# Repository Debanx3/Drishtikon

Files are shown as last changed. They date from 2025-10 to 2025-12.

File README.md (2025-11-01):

# Drishtikon:
## EdgeAI based human detection system <br>
 
+ The beginnings: ***Drishtikon*** is a framework consisting of two modules, the mainboard and the controller modules that can be powered directly from the 220VAC mains in dorms, libraries and canteens. The two boards communicate with each other using a BLE protocol and the mainboard is connected to the internet via Wi-Fi, it connects to the local network using hard coding.<br> <br>
  <div>
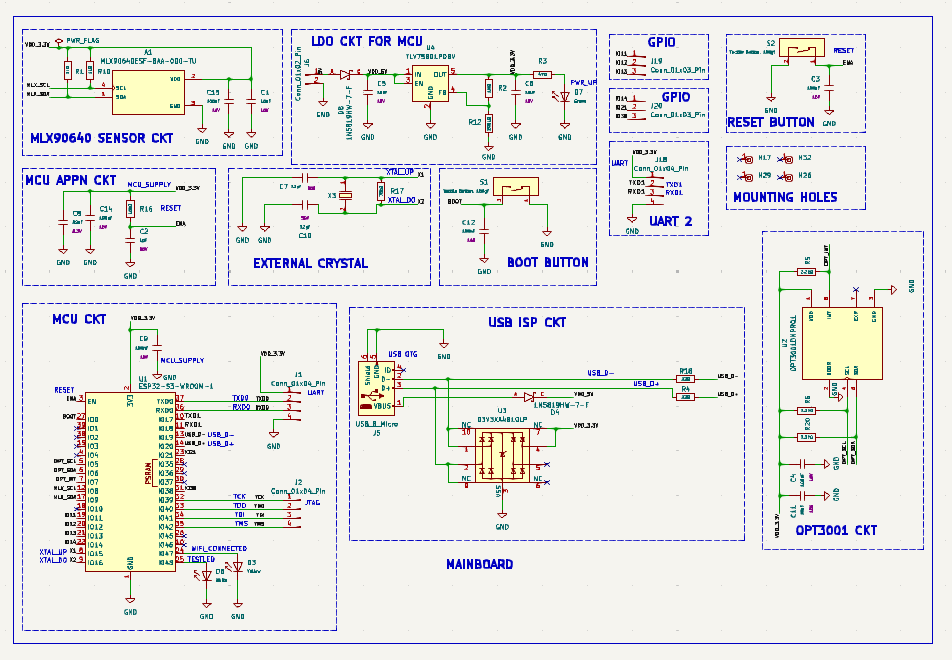
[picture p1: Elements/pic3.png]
  
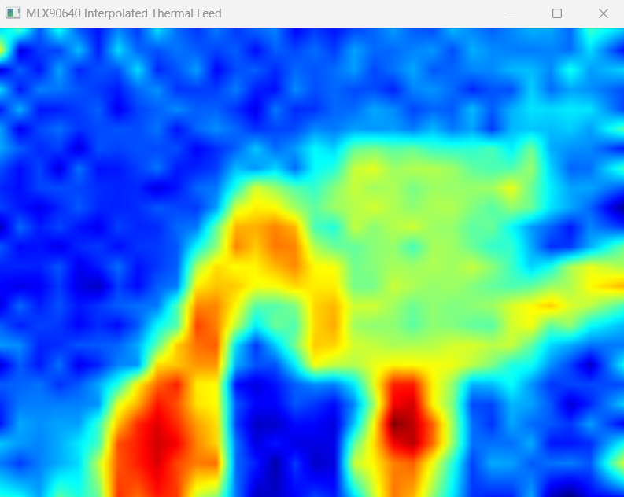
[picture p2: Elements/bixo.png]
  
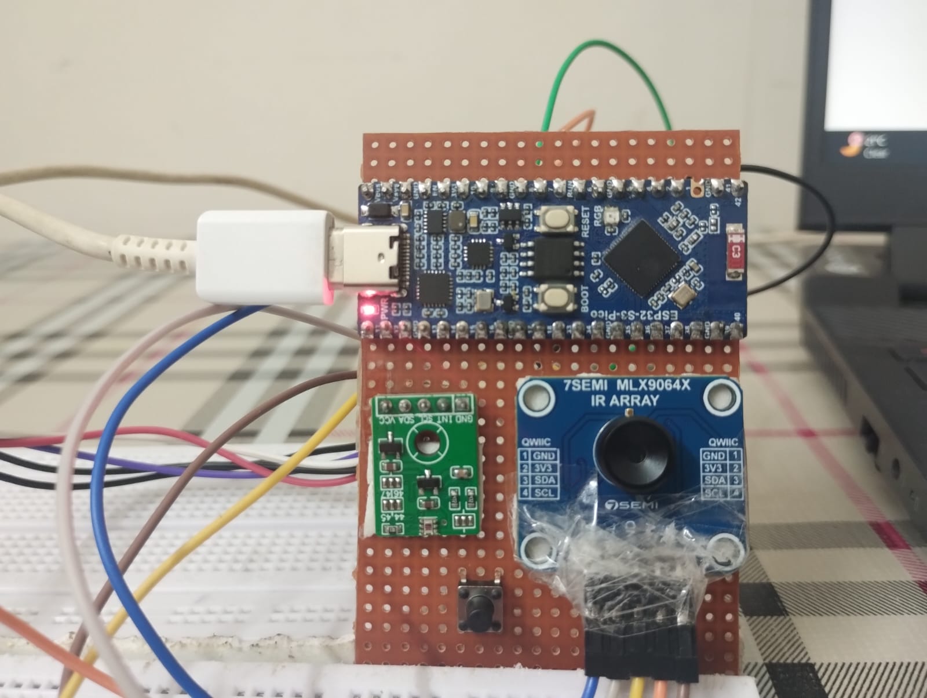
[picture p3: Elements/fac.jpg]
  
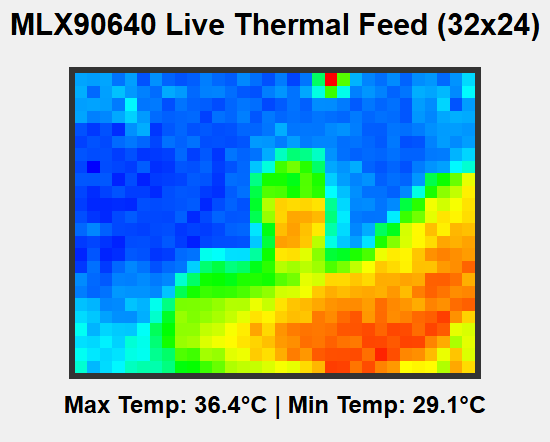
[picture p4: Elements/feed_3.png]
  
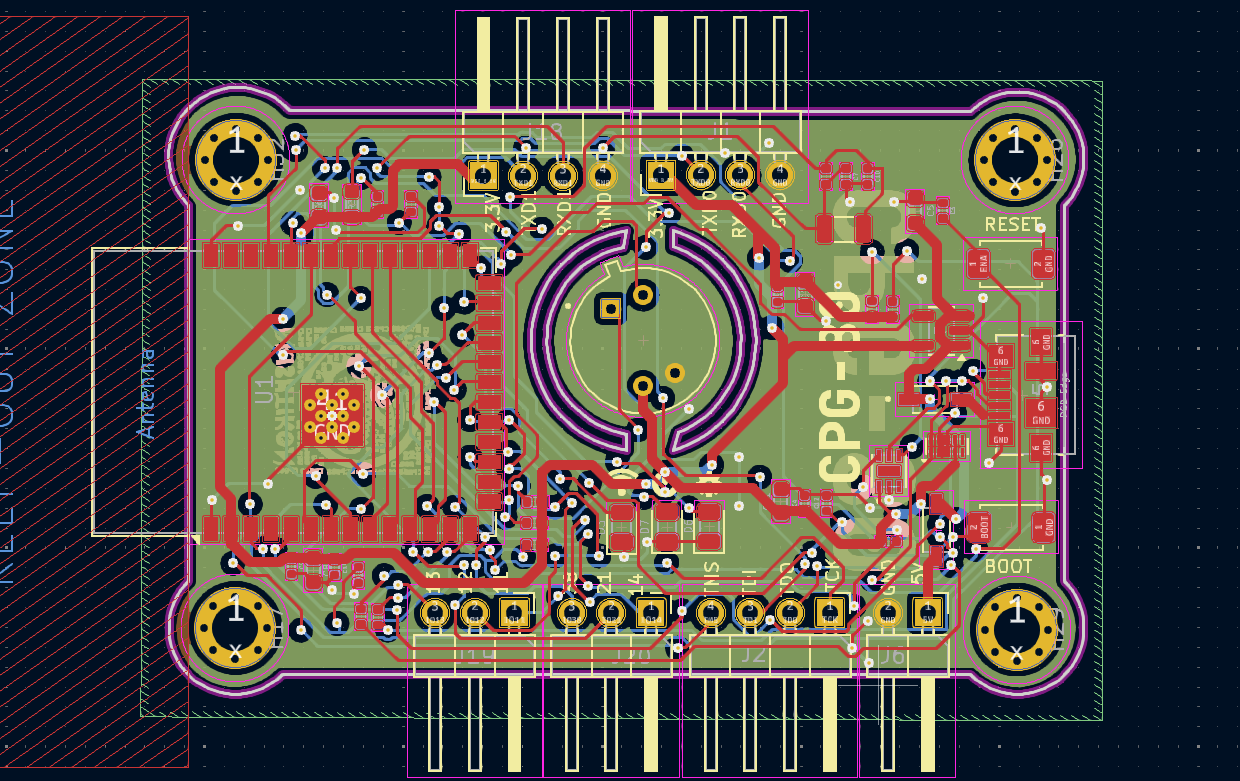
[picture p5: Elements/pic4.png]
  
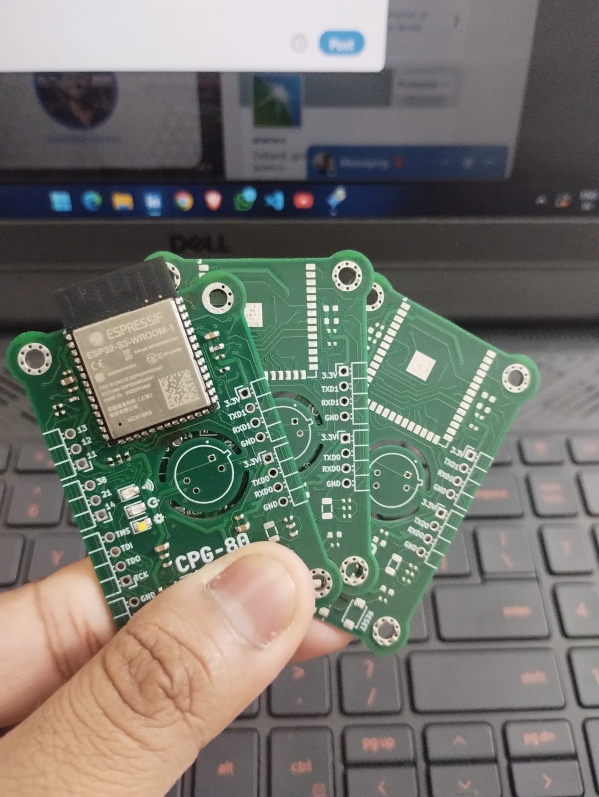
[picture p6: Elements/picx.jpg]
  
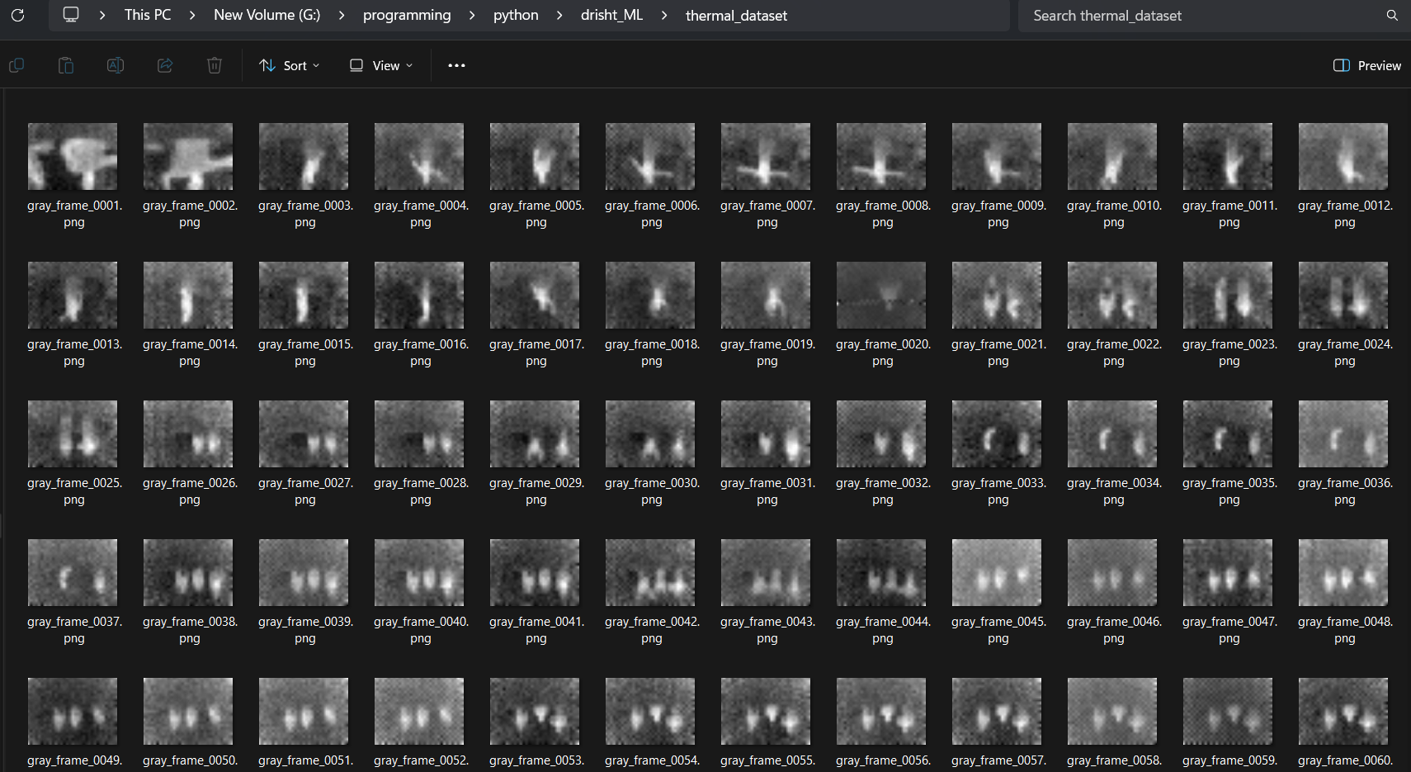
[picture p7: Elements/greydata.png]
  
  </div>

* License: MIT License
* Contact/Credits: Debanil Chanda, [DebanX3@github.com](mailto:debanx3@github.com)

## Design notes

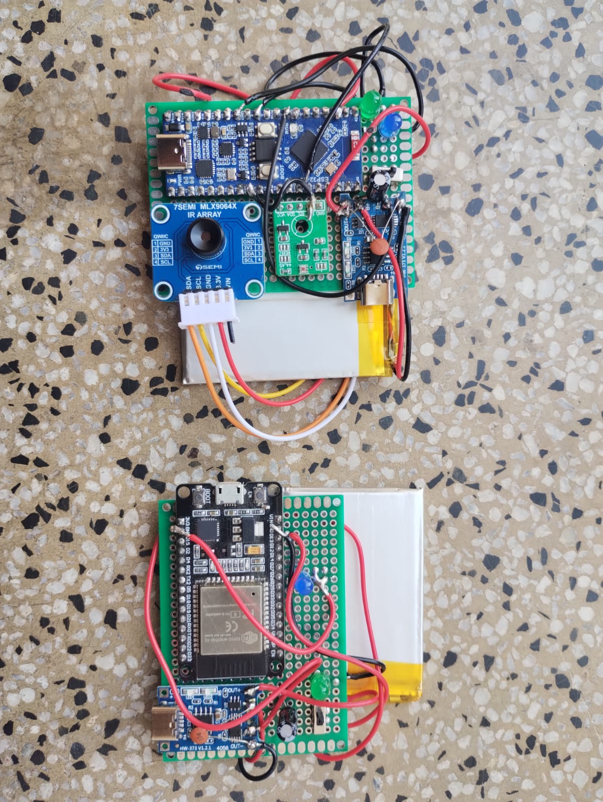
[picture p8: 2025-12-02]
Source_Code/Elements/A/drishtikon.jpg

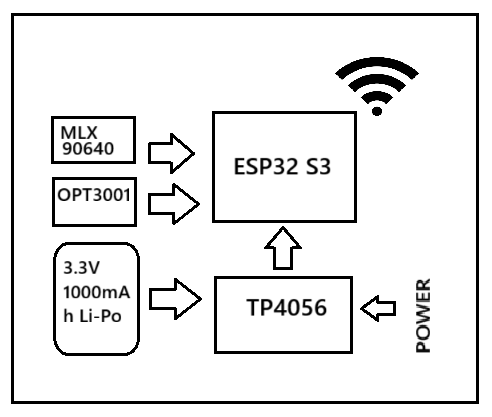
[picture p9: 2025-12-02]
Source_Code/Processing unit/pros.png

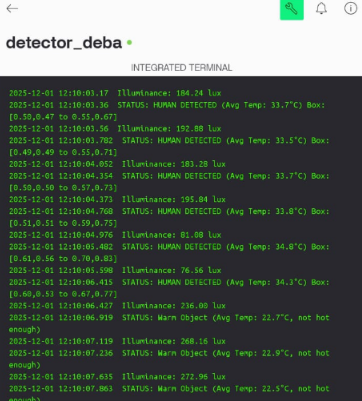
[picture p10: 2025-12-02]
Source_Code/Elements/A/blynk.png

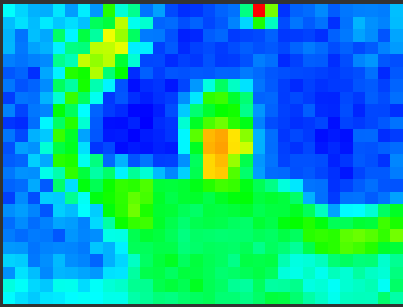
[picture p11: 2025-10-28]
Elements/feed_1.png

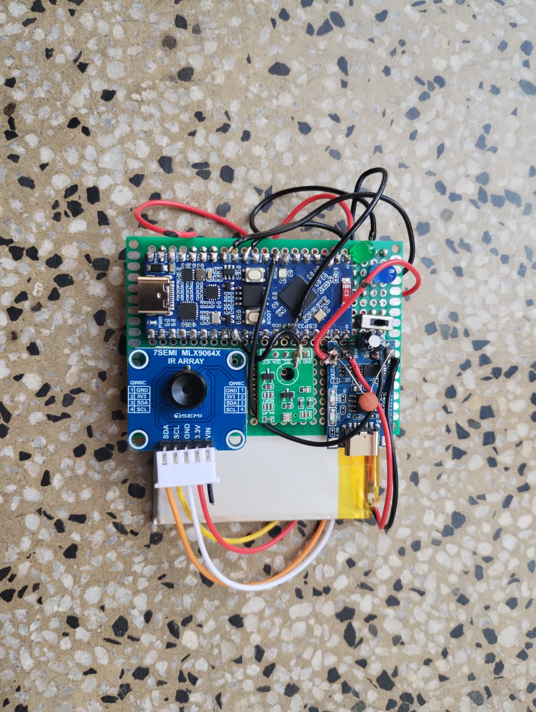
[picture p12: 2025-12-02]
Source_Code/Elements/A/processing.jpg

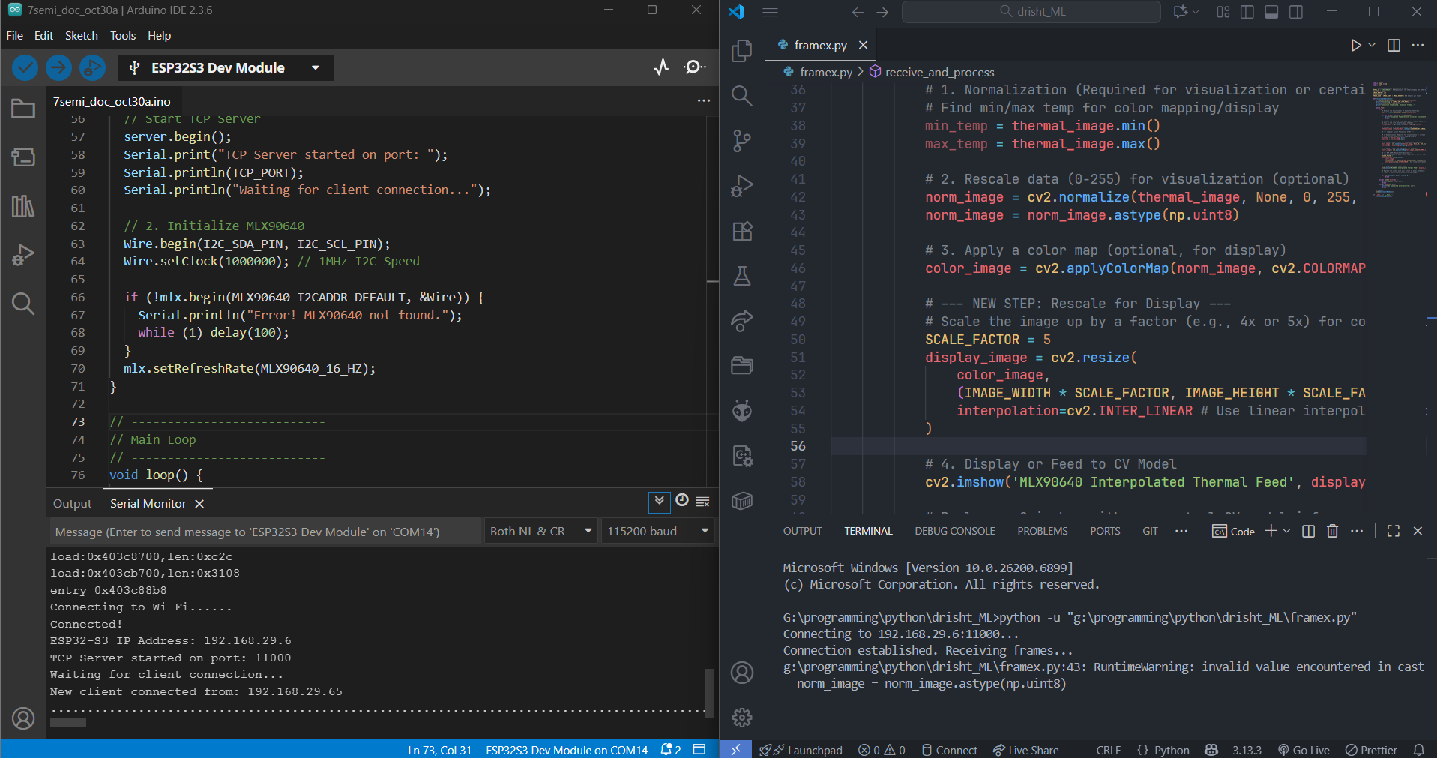
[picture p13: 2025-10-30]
Elements/bobu.png

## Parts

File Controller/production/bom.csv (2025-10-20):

Designator | Footprint | Quantity | Value | LCSC Part #
C13, C16, C19, C25 | C_0402 | 4 | 100nF | C1525
C17, C21 | C_0603 | 2 | 10uF | C19702
C18, C24 | C_0402 | 2 | 12pF | C1547
C20 | C_0402 | 1 | 1pF | C1550
C23 | C_0603 | 1 | 22uF | C59461
D1 | D_0805 | 1 | Green | C2297
D10, D9 | SOD3715X145N | 2 | 1N5819HW-7-F
D2 | D_0805 | 1 | White | C34499
D5 | D_0805 | 1 | Yellow | C2296
H22, H23, H24, H25 | Hole, 3mm | 4 | ~
J10, J9 | PinHeader_1x04_P2.54mm_Horizontal | 2 | Conn_01x04_Pin
J11 | USB_Micro-B_Molex_47346-0001 | 1 | USB_B_Micro
J13, J14, J15, J16 | PinHeader_1x05_P2.54mm_Vertical | 4 | Conn_01x05_Socket
J8 | PinHeader_1x02_P2.54mm_Horizontal | 1 | Conn_01x02_Pin
R11 | R_0603 | 1 | 47Ω | C23182
R14 | R_0402 | 1 | 1MΩ | C26083
R15 | R_0402 | 1 | 200kΩ | C25764
R19, R7 | R_0402 | 2 | 22Ω | C25092
R8 | R_0402 | 1 | 10kΩ | C25744
R9 | R_0402 | 1 | 75kΩ | C25798
S3, S4 | SW_TS-1088-AR02016 | 2 | Tactile Button, 160gf | C720477
U5 | ESP32-S3-WROOM-1 | 1 | ESP32-S3-WROOM-1
U6 | SOT-23-5 | 1 | TLV75801PDBV
U7 | Diodes_UDFN-10_1.0x2.5mm_P0.5mm | 1 | D3V3XA4B10LP
X1 | FC-135R_L3.2-W1.5 | 1 | Q13FC1350000400 | C32346

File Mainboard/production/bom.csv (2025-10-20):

Designator | Footprint | Quantity | Value | LCSC Part #
A1 | TO292P930H600-4 | 1 | MLX90640ESF-BAA-000-TU
C1, C11, C5, C6 | C_0603 | 4 | 10uF | C19702
C10, C7 | C_0402 | 2 | 12pF | C1547
C12, C14, C15, C3, C4, C9 | C_0402 | 6 | 100nF | C1525
C2 | C_0402 | 1 | 1pF | C1550
C8 | C_0603 | 1 | 22uF | C59461
D3 | D_0805 | 1 | Yellow | C2296
D4, D8 | SOD3715X145N | 2 | 1N5819HW-7-F
D6 | D_0805 | 1 | White | C34499
D7 | D_0805 | 1 | Green | C2297
H17, H26, H29, H32 | Hole, 3mm | 4 | ~
J1, J18, J2 | PinHeader_1x04_P2.54mm_Horizontal | 3 | Conn_01x04_Pin
J19, J20 | PinHeader_1x03_P2.54mm_Horizontal | 2 | Conn_01x03_Pin
J5 | USB_Micro-B_Molex_47346-0001 | 1 | USB_B_Micro
J6 | PinHeader_1x02_P2.54mm_Horizontal | 1 | Conn_01x02_Pin
R1, R10 | R_0402 | 2 | 1kΩ | C11702
R12 | R_0402 | 1 | 200kΩ | C25764
R16 | R_0402 | 1 | 10kΩ | C25744
R17 | R_0402 | 1 | 75kΩ | C25798
R18, R4 | R_0402 | 2 | 22Ω | C25092
R2 | R_0402 | 1 | 1MΩ | C26083
R20, R5, R6 | R_0402 | 3 | 2.2kΩ | C25879
R3 | R_0603 | 1 | 47Ω | C23182
S1, S2 | SW_TS-1088-AR02016 | 2 | Tactile Button, 160gf | C720477
U1 | ESP32-S3-WROOM-1 | 1 | ESP32-S3-WROOM-1
U2 | SON65P200X200X65-7N | 1 | OPT3001DNPRQ1
U3 | Diodes_UDFN-10_1.0x2.5mm_P0.5mm | 1 | D3V3XA4B10LP
U4 | SOT-23-5 | 1 | TLV75801PDBV
X3 | FC-135R_L3.2-W1.5 | 1 | Q13FC1350000400 | C32346

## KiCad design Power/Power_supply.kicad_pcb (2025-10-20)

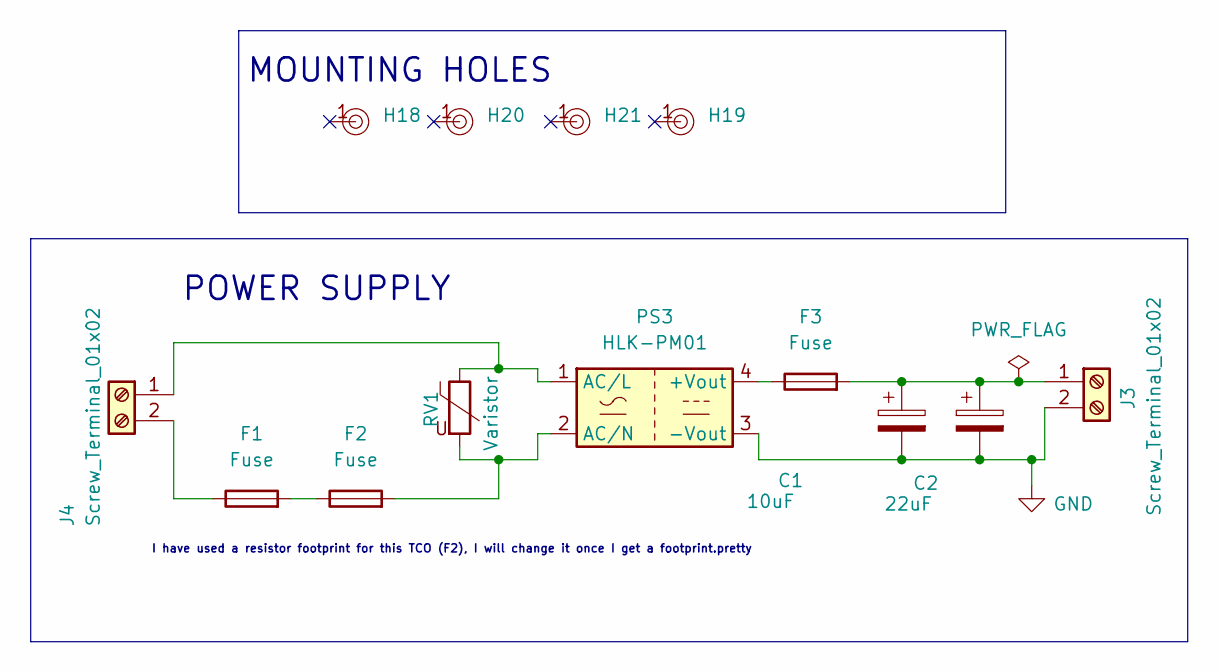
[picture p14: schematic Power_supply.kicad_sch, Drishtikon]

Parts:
C1: 10uF; CP_Radial_D8.0mm_P3.50mm
C2: 22uF; CP_Radial_D8.0mm_P3.50mm
F1, F3: Fuse; Fuseholder_Cylinder-5x20mm_Stelvio-Kontek_PTF78_Horizontal_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
F2: Fuse; R_Axial_DIN0309_L9.0mm_D3.2mm_P12.70mm_Horizontal
H18, H19, H20, H21: Hole, 3mm
J3, J4: Screw_Terminal_01x02; TerminalBlock_Phoenix_MKDS-1,5-2-5.08_1x02_P5.08mm_Horizont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
PS3: HLK-PM01; Converter_ACDC_Hi-Link_HLK-PMxx
RV1: Varistor; RV_Disc_D12mm_W3.9mm_P7.5mm

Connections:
GND: C1.2, C2.2, J3.2, PS3.3 (-Vout)
unnamed: F1.2, F2.1
unnamed: C1.1, C2.1, F3.2, J3.1
unnamed: J4.1, PS3.1 (AC/L), RV1.1
unnamed: F1.1, J4.2
unnamed: F3.1, PS3.4 (+Vout)
unnamed: F2.2, PS3.2 (AC/N), RV1.2

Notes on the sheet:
I have used a resistor footprint for this TCO (F2), I will change it once I get a footprint.pretty
POWER SUPPLY
MOUNTING HOLES

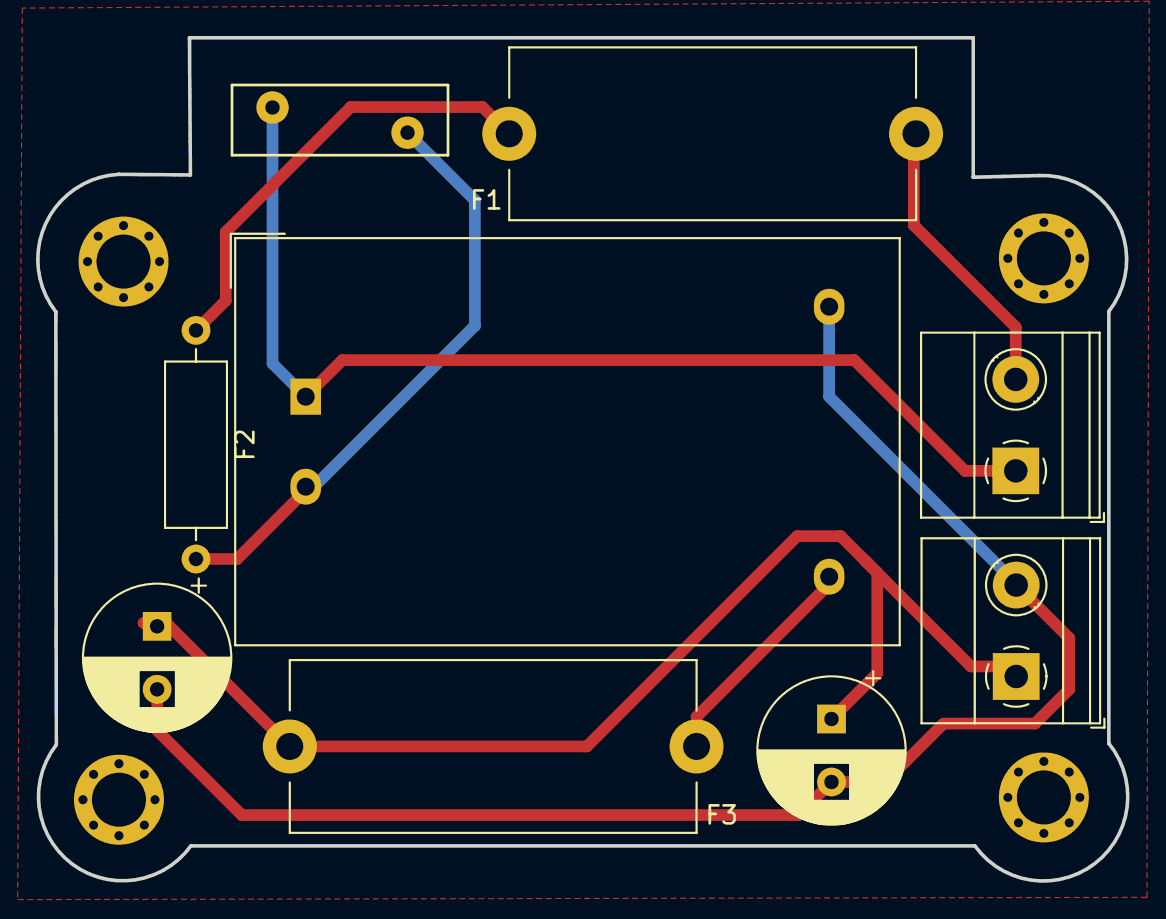
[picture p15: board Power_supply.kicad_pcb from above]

Board: 2 copper layers, 60.6 x 46.8 mm, 13 parts (0 on the bottom side), 7 nets.

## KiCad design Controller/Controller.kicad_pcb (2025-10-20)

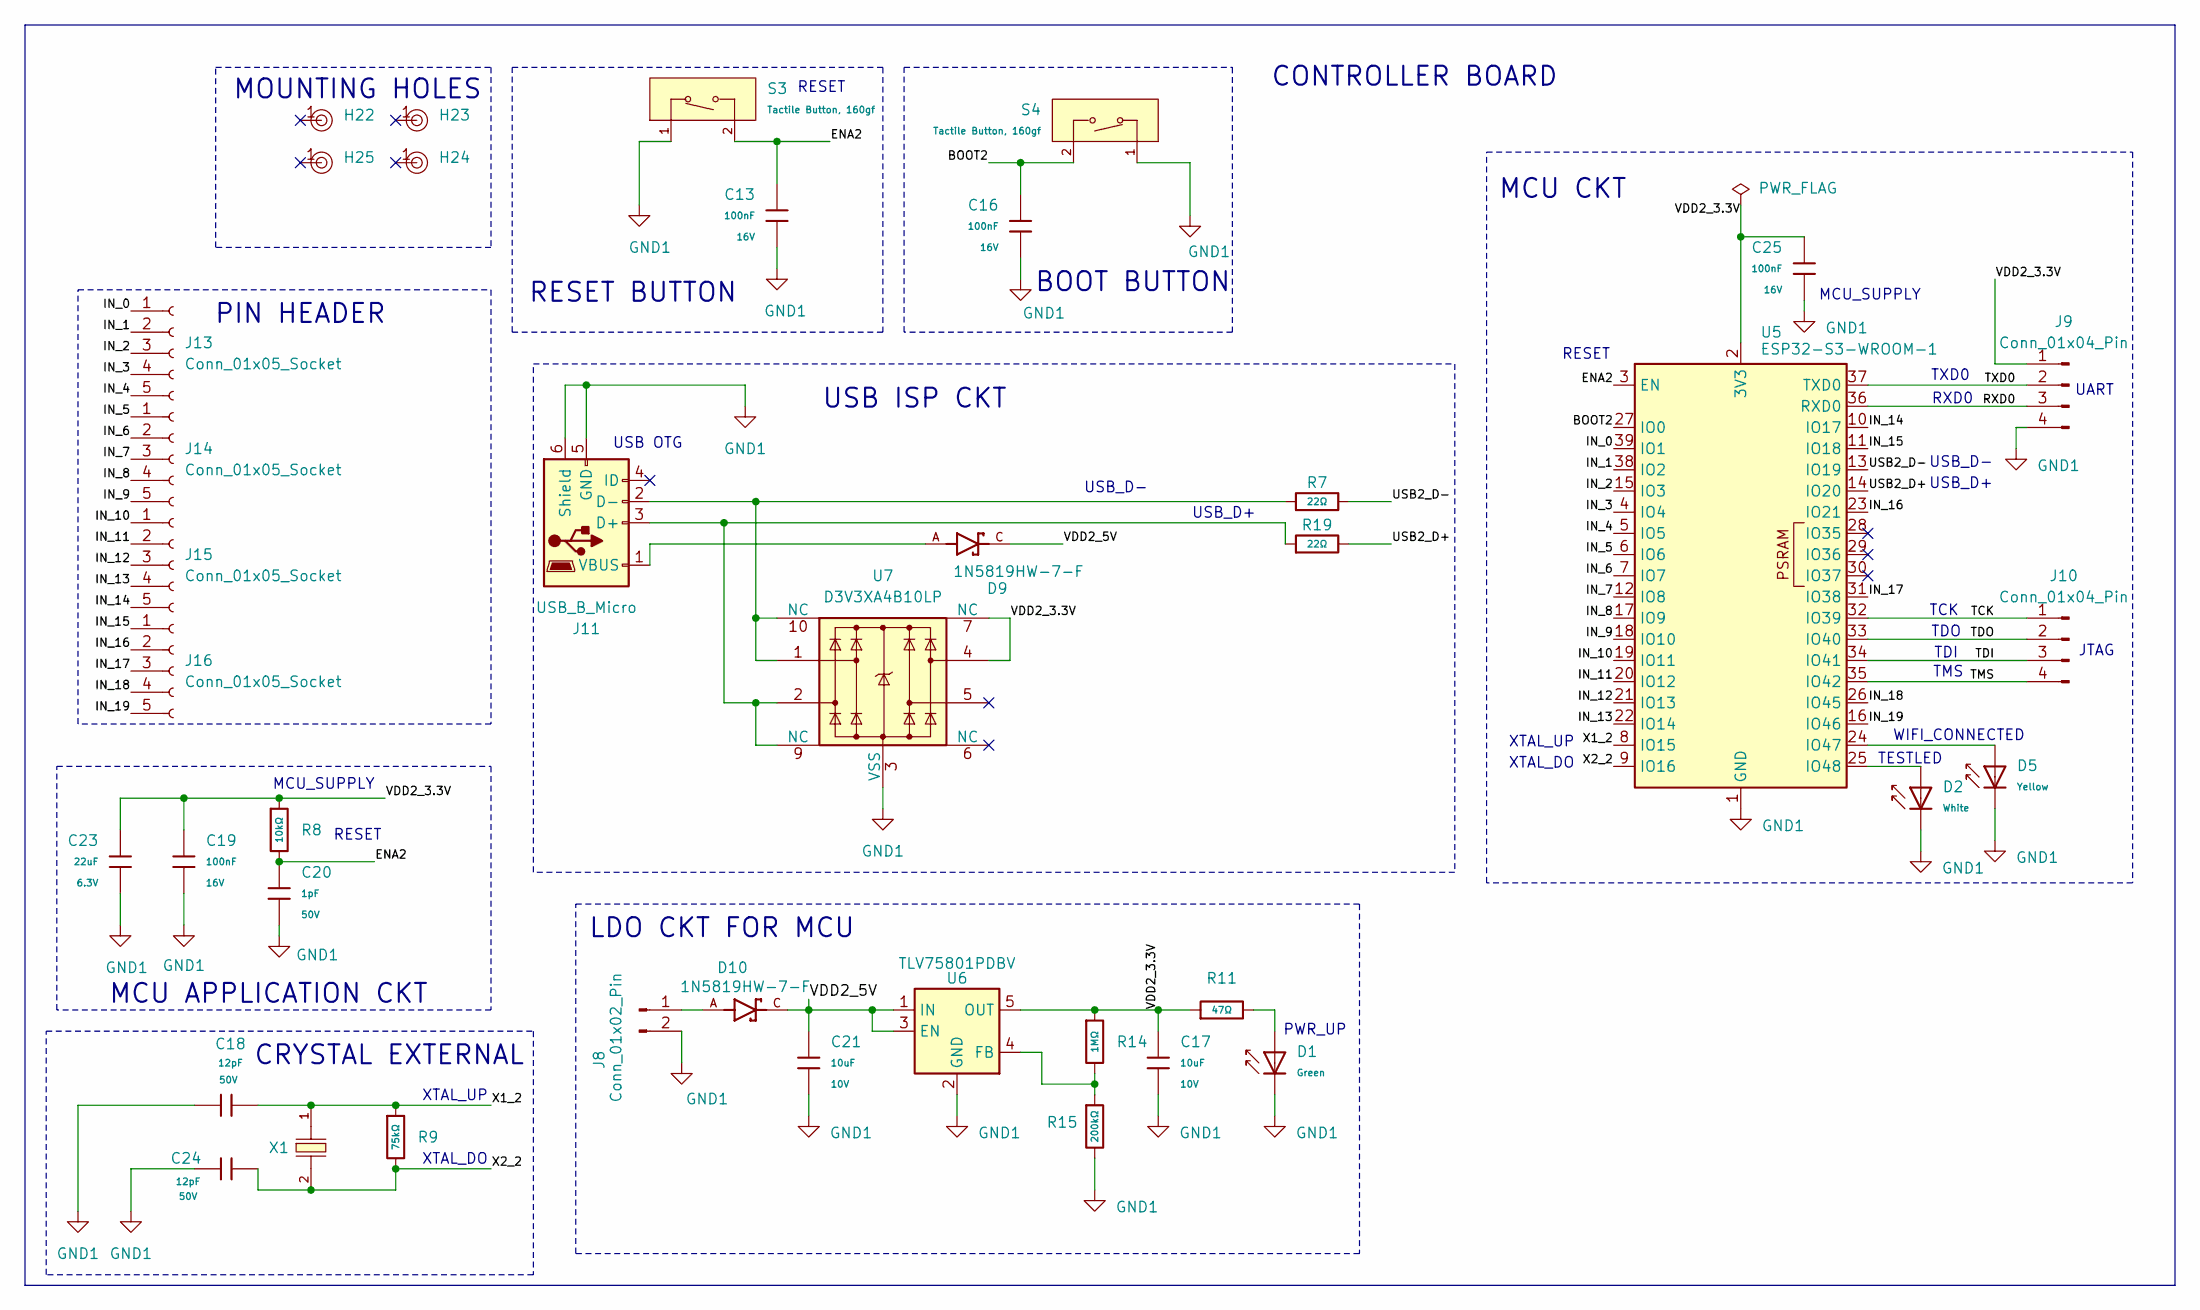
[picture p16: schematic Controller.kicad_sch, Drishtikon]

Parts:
C13, C16, C19, C25: 100nF; C_0402; Voltage Rated 16V; Tolerance ±10%; Part CL05B104KO5NNNC; LCSC C1525
C17, C21: 10uF; C_0603; Voltage Rated 10V; Tolerance ±10%; Part CL10A106KP8NNNC; LCSC C19702
C18, C24: 12pF; C_0402; Voltage Rated 50V; Tolerance ±5%; Part 0402CG120J500NT; LCSC C1547
C20: 1pF; C_0402; Voltage Rated 50V; Part 0402CG1R0C500NT; LCSC C1550
C23: 22uF; C_0603; Voltage Rated 6.3V; Tolerance ±20%; Part CL10A226MQ8NRNC; LCSC C59461
D1: Green; D_0805; Part KT-0805G; LCSC C2297
D2: White; D_0805; Part KT-0805W; LCSC C34499
D5: Yellow; D_0805; Part KT-0805Y; LCSC C2296
D9, D10: 1N5819HW-7-F; SOD3715X145N; PARTREV 18-2
H22, H23, H24, H25: Hole, 3mm
J8: Conn_01x02_Pin; PinHeader_1x02_P2.54mm_Horizontal
J9, J10: Conn_01x04_Pin; PinHeader_1x04_P2.54mm_Horizontal
J11: USB_B_Micro; USB_Micro-B_Molex_47346-0001
J13, J14, J15, J16: Conn_01x05_Socket; PinHeader_1x05_P2.54mm_Vertical
R7, R19: 22Ω; R_0402; Overload Voltage (Max) 50V; Tolerance ±1%; Part 0402WGF220JTCE; LCSC C25092
R8: 10kΩ; R_0402; Overload Voltage (Max) 50V; Tolerance ±1%; Part 0402WGF1002TCE; LCSC C25744
R9: 75kΩ; R_0402; Overload Voltage (Max) 50V; Tolerance ±1%; Part 0402WGF7502TCE; LCSC C25798
R11: 47Ω; R_0603; Overload Voltage (Max) 75V; Tolerance ±1%; Part 0603WAF470JT5E; LCSC C23182
R14: 1MΩ; R_0402; Overload Voltage (Max) 50V; Tolerance ±1%; Part 0402WGF1004TCE; LCSC C26083
R15: 200kΩ; R_0402; Overload Voltage (Max) 50V; Tolerance ±1%; Part 0402WGF2003TCE; LCSC C25764
S3, S4: Tactile Button, 160gf; SW_TS-1088-AR02016; Voltage Rating (Dc) 12V; Part TS-1088-AR02016; LCSC C720477
U5: ESP32-S3-WROOM-1
U6: TLV75801PDBV; SOT-23-5
U7: D3V3XA4B10LP; Diodes_UDFN-10_1.0x2.5mm_P0.5mm
X1: Q13FC1350000400; FC-135R_L3.2-W1.5; Frequency Tolerance ±20ppm; Part Q13FC13500004; LCSC C32346

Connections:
/BOOT2: C16.1, S4.2 (B), U5.27 (IO0)
/ENA2: C13.1, C20.2, R8.2, S3.2 (B), U5.3 (EN)
/IN_0: J13.1, U5.39 (IO1)
/IN_1: J13.2, U5.38 (IO2)
/IN_2: J13.3, U5.15 (IO3)
/IN_3: J13.4, U5.4 (IO4)
/IN_4: J13.5, U5.5 (IO5)
/IN_5: J14.1, U5.6 (IO6)
/IN_6: J14.2, U5.7 (IO7)
/IN_7: J14.3, U5.12 (IO8)
/IN_8: J14.4, U5.17 (IO9)
/IN_9: J14.5, U5.18 (IO10)
/IN_10: J15.1, U5.19 (IO11)
/IN_11: J15.2, U5.20 (IO12)
/IN_12: J15.3, U5.21 (IO13)
/IN_13: J15.4, U5.22 (IO14)
/IN_14: J15.5, U5.10 (IO17)
/IN_15: J16.1, U5.11 (IO18)
/IN_16: J16.2, U5.23 (IO21)
/IN_17: J16.3, U5.31 (IO38)
/IN_18: J16.4, U5.26 (IO45)
/IN_19: J16.5, U5.16 (IO46)
/RXD0: J9.3, U5.36 (RXD0)
/TCK: J10.1, U5.32 (IO39)
/TDI: J10.3, U5.34 (IO41)
/TDO: J10.2, U5.33 (IO40)
/TMS: J10.4, U5.35 (IO42)
/TXD0: J9.2, U5.37 (TXD0)
/USB2_D+: R19.2, U5.14 (IO20)
/USB2_D-: R7.2, U5.13 (IO19)
/VDD2_3.3V: C17.1, C19.1, C23.1, C25.1, J9.1, R8.1, R11.1, R14.1, U5.2 (3V3), U6.5 (OUT), U7.4, U7.7 (NC)
/VDD2_5V: C21.1, D9.C, D10.C, U6.1 (IN), U6.3 (EN)
/X1_2: C18.2, R9.1, U5.8 (IO15), X1.1
/X2_2: C24.2, R9.2, U5.9 (IO16), X1.2
GND1: C13.2, C16.2, C17.2, C18.1, C19.2, C20.1, C21.2, C23.2, C24.1, C25.2, D1.1, D2.1, D5.1, J8.2, J9.4, J11.5 (GND), J11.6 (Shield), R15.2, S3.1 (A), S4.1 (A), U5.1 (GND), U5.40 (GND), U5.41 (GND), U6.2 (GND), U7.3 (VSS), U7.8 (VSS)
unnamed: D1.2, R11.2
unnamed: D10.A, J8.1
unnamed: J11.3 (D+), R19.1, U7.2, U7.9 (NC)
unnamed: J11.2 (D-), R7.1, U7.1, U7.10 (NC)
unnamed: D9.A, J11.1 (VBUS)
unnamed: D5.2, U5.24 (IO47)
unnamed: D2.2, U5.25 (IO48)
unnamed: R14.2, R15.1, U6.4 (FB)

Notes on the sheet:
RESET
MCU_SUPPLY
UART
MCU CKT
TMS
TDI
MCU APPLICATION CKT
TDO
USB_D+
TESTLED
JTAG
BOOT BUTTON
LDO CKT FOR MCU
CONTROLLER BOARD
RESET BUTTON
WIFI_CONNECTED
MOUNTING HOLES
USB_D-
CRYSTAL EXTERNAL
XTAL_UP
PWR_UP
PIN HEADER
USB ISP CKT
USB OTG
TCK
XTAL_DO
TXD0
RXD0

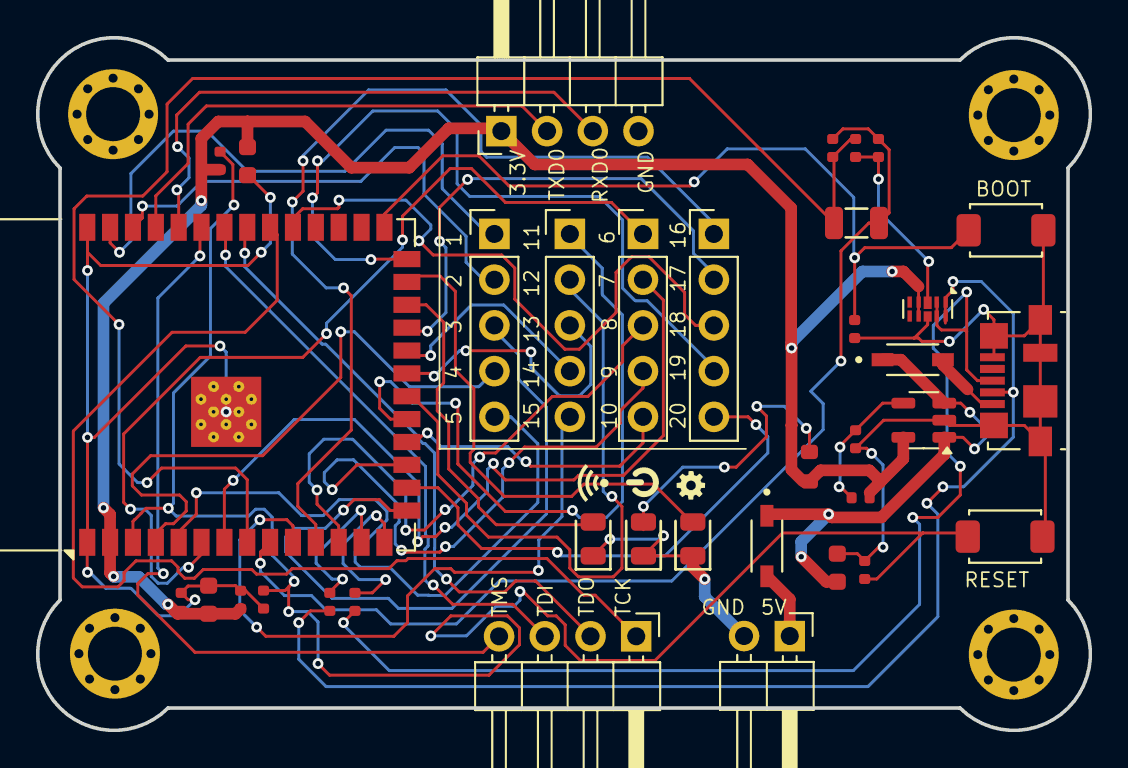
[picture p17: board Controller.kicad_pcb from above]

Board: 4 copper layers, 58.5 x 38.5 mm, 40 parts (0 on the bottom side), 43 nets.

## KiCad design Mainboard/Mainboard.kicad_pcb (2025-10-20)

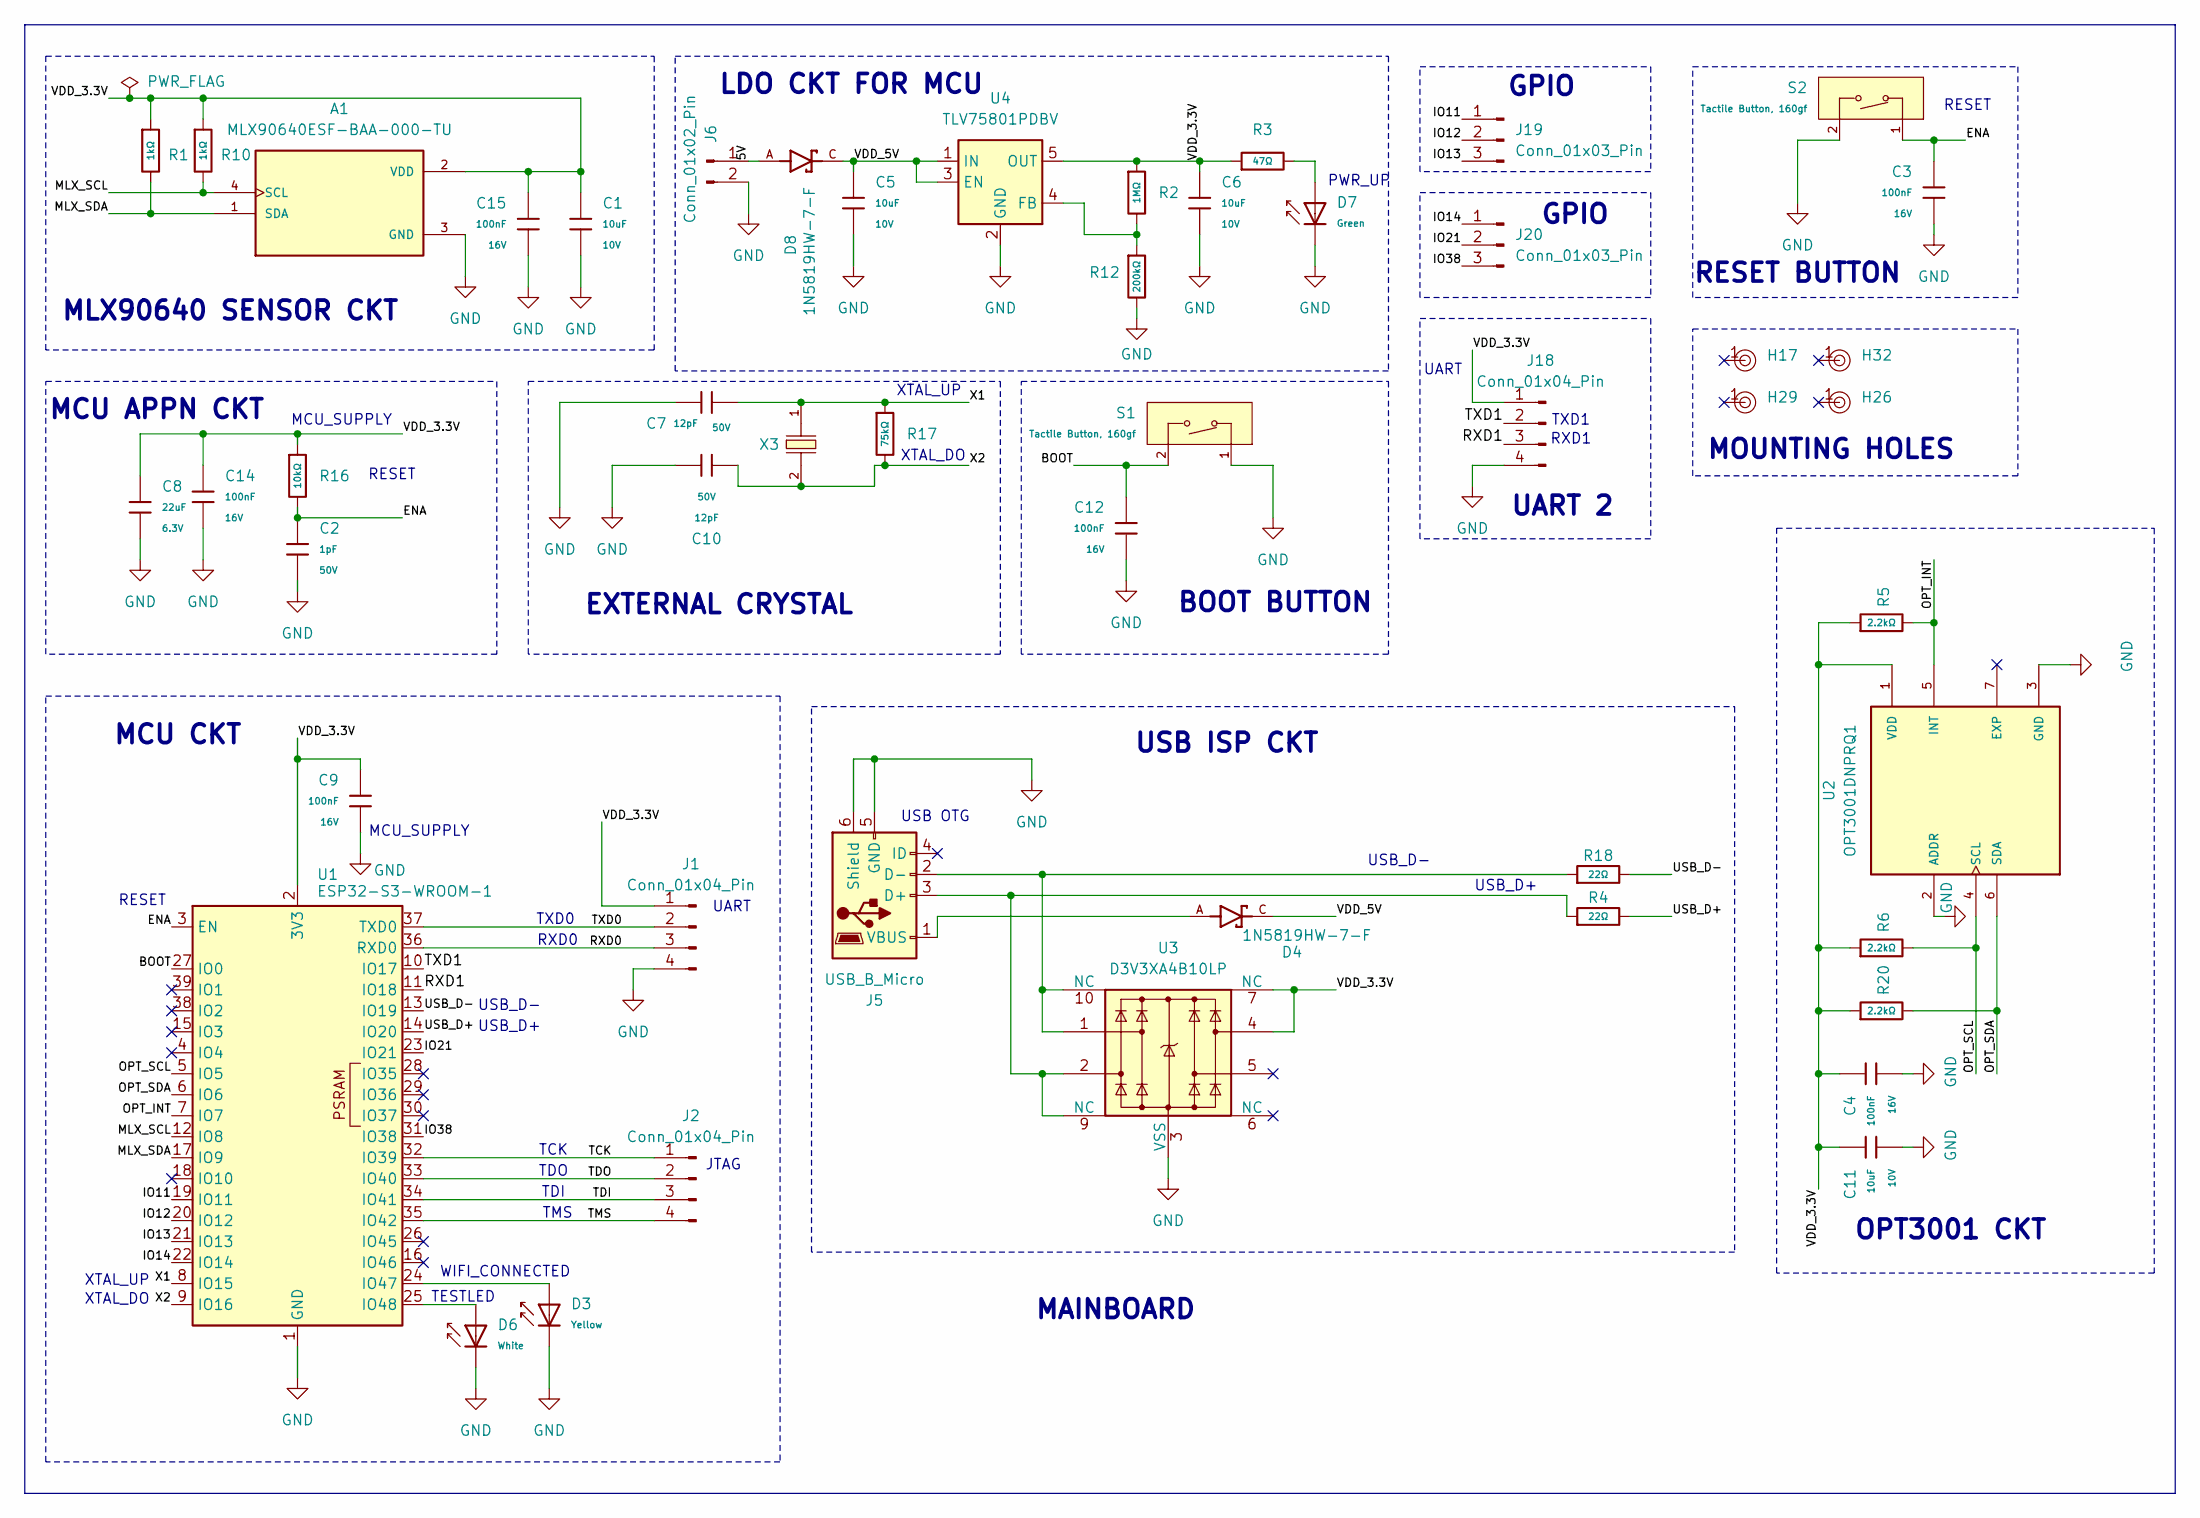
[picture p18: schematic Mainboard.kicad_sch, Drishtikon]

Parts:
A1: MLX90640ESF-BAA-000-TU; TO292P930H600-4; PARTREV 11
C1, C5, C6, C11: 10uF; C_0603; Voltage Rated 10V; Tolerance ±10%; Part CL10A106KP8NNNC; LCSC C19702
C2: 1pF; C_0402; Voltage Rated 50V; Part 0402CG1R0C500NT; LCSC C1550
C3, C4, C9, C12, C14, C15: 100nF; C_0402; Voltage Rated 16V; Tolerance ±10%; Part CL05B104KO5NNNC; LCSC C1525
C7, C10: 12pF; C_0402; Voltage Rated 50V; Tolerance ±5%; Part 0402CG120J500NT; LCSC C1547
C8: 22uF; C_0603; Voltage Rated 6.3V; Tolerance ±20%; Part CL10A226MQ8NRNC; LCSC C59461
D3: Yellow; D_0805; Part KT-0805Y; LCSC C2296
D4, D8: 1N5819HW-7-F; SOD3715X145N; PARTREV 18-2
D6: White; D_0805; Part KT-0805W; LCSC C34499
D7: Green; D_0805; Part KT-0805G; LCSC C2297
H17, H26, H29, H32: Hole, 3mm
J1, J2, J18: Conn_01x04_Pin; PinHeader_1x04_P2.54mm_Horizontal
J5: USB_B_Micro; USB_Micro-B_Molex_47346-0001
J6: Conn_01x02_Pin; PinHeader_1x02_P2.54mm_Horizontal
J19, J20: Conn_01x03_Pin; PinHeader_1x03_P2.54mm_Horizontal
R1, R10: 1kΩ; R_0402; Overload Voltage (Max) 50V; Tolerance ±1%; Part 0402WGF1001TCE; LCSC C11702
R2: 1MΩ; R_0402; Overload Voltage (Max) 50V; Tolerance ±1%; Part 0402WGF1004TCE; LCSC C26083
R3: 47Ω; R_0603; Overload Voltage (Max) 75V; Tolerance ±1%; Part 0603WAF470JT5E; LCSC C23182
R4, R18: 22Ω; R_0402; Overload Voltage (Max) 50V; Tolerance ±1%; Part 0402WGF220JTCE; LCSC C25092
R5, R6, R20: 2.2kΩ; R_0402; Overload Voltage (Max) 50V; Tolerance ±1%; Part 0402WGF2201TCE; LCSC C25879
R12: 200kΩ; R_0402; Overload Voltage (Max) 50V; Tolerance ±1%; Part 0402WGF2003TCE; LCSC C25764
R16: 10kΩ; R_0402; Overload Voltage (Max) 50V; Tolerance ±1%; Part 0402WGF1002TCE; LCSC C25744
R17: 75kΩ; R_0402; Overload Voltage (Max) 50V; Tolerance ±1%; Part 0402WGF7502TCE; LCSC C25798
S1, S2: Tactile Button, 160gf; SW_TS-1088-AR02016; Voltage Rating (Dc) 12V; Part TS-1088-AR02016; LCSC C720477
U1: ESP32-S3-WROOM-1
U2: OPT3001DNPRQ1; SON65P200X200X65-7N; PARTREV 01/2018
U3: D3V3XA4B10LP; Diodes_UDFN-10_1.0x2.5mm_P0.5mm
U4: TLV75801PDBV; SOT-23-5
X3: Q13FC1350000400; FC-135R_L3.2-W1.5; Frequency Tolerance ±20ppm; Part Q13FC13500004; LCSC C32346

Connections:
/5V: D8.A, J6.1
/BOOT: C12.1, S1.2 (B), U1.27 (IO0)
/ENA: C2.2, C3.1, R16.2, S2.1 (A), U1.3 (EN)
/IO11: J19.1, U1.19 (IO11)
/IO12: J19.2, U1.20 (IO12)
/IO13: J19.3, U1.21 (IO13)
/IO14: J20.1, U1.22 (IO14)
/IO21: J20.2, U1.23 (IO21)
/IO38: J20.3, U1.31 (IO38)
/MLX_SCL: A1.4 (SCL), R10.2, U1.12 (IO8)
/MLX_SDA: A1.1 (SDA), R1.2, U1.17 (IO9)
/OPT_INT: R5.2, U1.7 (IO7), U2.5 (INT)
/OPT_SCL: R6.2, U1.5 (IO5), U2.4 (SCL)
/OPT_SDA: R20.2, U1.6 (IO6), U2.6 (SDA)
/RXD0: J1.3, U1.36 (RXD0)
/RXD1: J18.3, U1.11 (IO18)
/TCK: J2.1, U1.32 (IO39)
/TDI: J2.3, U1.34 (IO41)
/TDO: J2.2, U1.33 (IO40)
/TMS: J2.4, U1.35 (IO42)
/TXD0: J1.2, U1.37 (TXD0)
/TXD1: J18.2, U1.10 (IO17)
/USB_D+: R4.2, U1.14 (IO20)
/USB_D-: R18.2, U1.13 (IO19)
/VDD_3.3V: A1.2 (VDD), C1.1, C4.1, C6.1, C8.1, C9.1, C11.1, C14.1, C15.1, J1.1, J18.1, R1.1, R2.1, R3.1, R5.1, R6.1, R10.1, R16.1, R20.1, U1.2 (3V3), U2.1 (VDD), U3.4, U3.7 (NC), U4.5 (OUT)
/VDD_5V: C5.1, D4.C, D8.C, U4.1 (IN), U4.3 (EN)
/X1: C7.2, R17.1, U1.8 (IO15), X3.1
/X2: C10.2, R17.2, U1.9 (IO16), X3.2
GND: A1.3 (GND), C1.2, C2.1, C3.2, C4.2, C5.2, C6.2, C7.1, C8.2, C9.2, C10.1, C11.2, C12.2, C14.2, C15.2, D3.1, D6.1, D7.1, J1.4, J5.5 (GND), J5.6 (Shield), J6.2, J18.4, R12.2, S1.1 (A), S2.2 (B), U1.1 (GND), U1.40 (GND), U1.41 (GND), U2.2 (ADDR), U2.3 (GND), U3.3 (VSS), U3.8 (VSS), U4.2 (GND)
unnamed: D7.2, R3.2
unnamed: J5.3 (D+), R4.1, U3.2, U3.9 (NC)
unnamed: J5.2 (D-), R18.1, U3.1, U3.10 (NC)
unnamed: D4.A, J5.1 (VBUS)
unnamed: D3.2, U1.24 (IO47)
unnamed: D6.2, U1.25 (IO48)
unnamed: R2.2, R12.1, U4.4 (FB)

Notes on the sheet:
OPT3001 CKT
LDO CKT FOR MCU
RXD0
PWR_UP
RESET
MCU_SUPPLY
MAINBOARD
XTAL_UP
GPIO
BOOT BUTTON
TDO
USB_D-
JTAG
USB ISP CKT
TXD0
UART
RXD1
MOUNTING HOLES
WIFI_CONNECTED
TCK
EXTERNAL CRYSTAL
TXD1
TDI
MCU CKT
RESET BUTTON
TESTLED
USB OTG
UART 2
XTAL_DO
MCU APPN CKT
USB_D+
TMS
MLX90640 SENSOR CKT

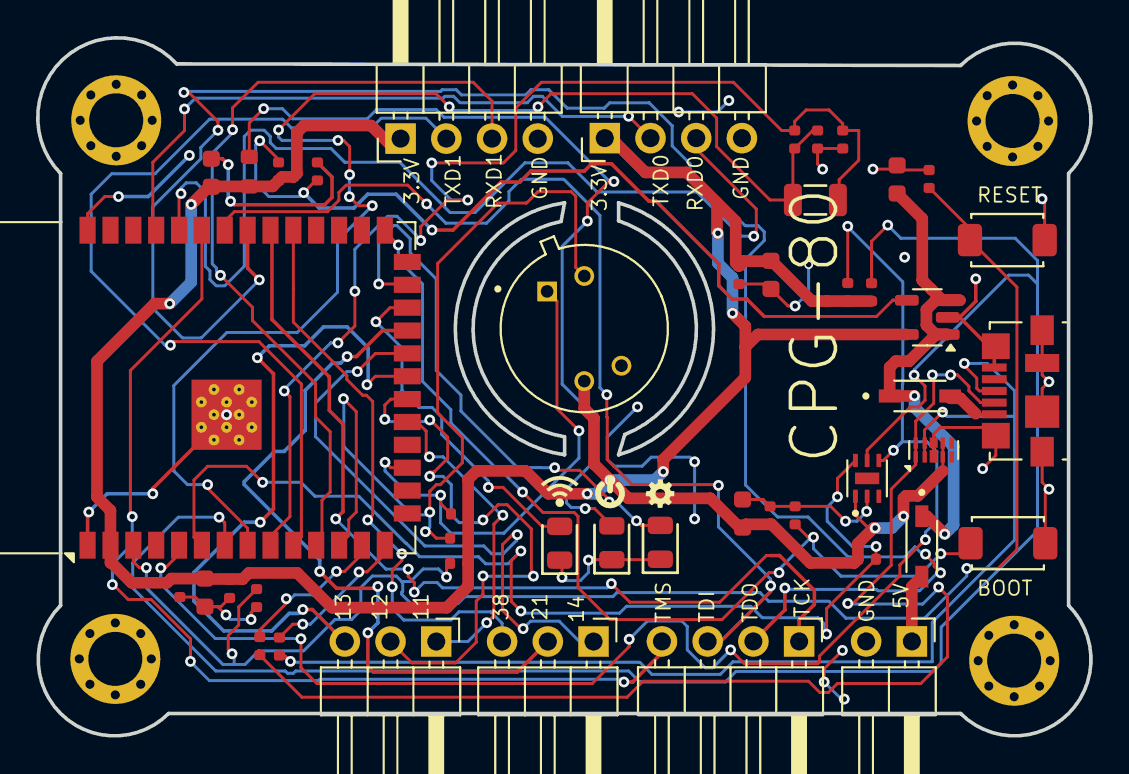
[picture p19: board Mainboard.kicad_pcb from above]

Board: 4 copper layers, 58.5 x 38.8 mm, 50 parts (0 on the bottom side), 36 nets.

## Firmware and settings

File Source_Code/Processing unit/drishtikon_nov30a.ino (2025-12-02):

//FULL CORRECTED DRISHTIKON DETECTOR SIDE CODE RUNNING SUCCESSFULLY ON SERIAL TERMINAL AND BLINK TERMINAL WIDGET
//WITH NEW DEVICE AND UPDATED AUTH TOKENS

/**************************************************************
 * DETECTOR DEVICE SKETCH (ESP32-S3)
 * MLX90640 and OPT3001 with TensorFlow Lite and Blynk Integration.
 **************************************************************/

// =============================================================
// ⚡ BLYNK INTEGRATION START
// =============================================================

// BLYNK CREDENTIALS - UPDATE THESE WITH YOUR ACTUAL VALUES
#define BLYNK_TEMPLATE_NAME "BUBBA"
#define BLYNK_TEMPLATE_ID   "TMPL3WgBo7eIO"   // Use the ID from your image
#define BLYNK_DEVICE_NAME   "detector_deba"           // Use the name for your Detector device
#define BLYNK_AUTH_TOKEN    "Ur6epRci-aIiDYLXdta9fKl2EKcgem5b" // Use the unique token for the Detector





#include <BlynkSimpleEsp32.h>
#include "Blynk/BlynkTimer.h" // Include the timer library

// --- BLYNK VIRTUAL PIN FOR LOGGING ---
#define VIRTUAL_PIN_TERMINAL V9
char logBuffer[256];


// Function to print text messages to both the Serial Monitor and the Blynk Terminal Widget
void blynkLog(const char* message) {
    Serial.println(message);
    // VIRTUAL_PIN_TERMINAL is V9
    Blynk.virtualWrite(VIRTUAL_PIN_TERMINAL, message); 
}


// Wi-Fi Credentials - UPDATE THESE WITH YOUR ACTUAL VALUES
char ssid[] = "ERROR";
char pass[] = "skansal937";

BlynkTimer timer; // Timer object for periodic Blynk tasks

// Global variables to store the most recent sensor data for sending
float current_lux = 0.0f;
float current_avg_temp = 0.0f;

// Function to send data to Blynk (called by the timer)
void sendSensorDataToBlynk() {
  // Send Illuminance (lux) to Virtual Pin V0
  Blynk.virtualWrite(V0, current_lux);

  // Send Average Temperature (Avg Temp) to Virtual Pin V1
  Blynk.virtualWrite(V1, current_avg_temp);

  Serial.println(">>> Blynk Data Sent <<<");
  Serial.print("V0 (Lux): "); Serial.println(current_lux);
  Serial.print("V1 (Avg Temp): "); Serial.println(current_avg_temp);
}


// =============================================================
// ⚡ BLYNK INTEGRATION END
// =============================================================

//OPT and MLX full woking correct

/**
 * TensorFlow Lite Bounding Box Predictor
 * Sensor: MLX90640 (32x24 Thermal Array)
 * Note: Assumes the model was trained on 32x24 thermal data normalized between T_MIN and T_MAX.
 */

#include "mlx_sensor_model_quantized.h"
#include <tflm_esp32.h>
#include <eloquent_tinyml.h>
#include <Wire.h> // MLX90640 uses I2C
#include <Adafruit_MLX90640.h> // The MLX sensor library
#include <opt3001.h>


// --- PIN DEFINITIONS ---
// I2C Bus 1: MLX90640 (Kept on standard 'Wire' object)
#define MLX_SDA_PIN 8
#define MLX_SCL_PIN 9

// I2C Bus 2: OPT3001 (Moved to custom 'Wire_OPT' object)
#define OPT_SDA_PIN 11
#define OPT_SCL_PIN 10
#define OPT_INT_PIN 12

// ... (rest of the #defines for TF and global variables)

// --- I2C OBJECTS ---
// 1. OPT3001 will use the custom I2C object (Wire_OPT)
TwoWire Wire_OPT = TwoWire(1); // Use I2C port 0 for OPT (Custom pins 10, 11)

#define TF_NUM_OPS 10
#define ARENA_SIZE 60000

Eloquent::TF::Sequential<TF_NUM_OPS, ARENA_SIZE> tf;

//CRITICAL CHANGE: Dimensions match the MLX90640 sensor 
#define IMG_WIDTH 32
#define IMG_HEIGHT 24
#define INPUT_SIZE (IMG_WIDTH * IMG_HEIGHT) // 32 * 24 = 768

// Define normalization constants used during model training
// YOU MUST CONFIRM THESE VALUES based on your training data
const float T_MIN = 0.0f; // Minimum temp (C) used in training
const float T_MAX = 50.0f; // Maximum temp (C) used in training
const float T_RANGE = T_MAX - T_MIN;

// Sensor data buffers
float mlx_frame[INPUT_SIZE];// Buffer to hold raw MLX90640 temp readings (32x24)
float input_image[INPUT_SIZE];// Global array to feed the TFLite model

// Define the MLX90640 sensor object
Adafruit_MLX90640 mlx;
// Create sensor object
opt3001 sensor;

// I2C address (0x44, 0x45, 0x46, or 0x47)
const uint8_t I2C_ADDRESS = 0x44;








//-------------------------------------------------------------
// SETUP
//-------------------------------------------------------------

void setup() {
    Serial.begin(115200);
    delay(1500);

    // 1. --- I2C Initialization for MLX90640 (Pins 8, 9) ---
    // The standard 'Wire' object is used and initialized to MLX pins.
    Wire.begin(MLX_SDA_PIN, MLX_SCL_PIN);

    Serial.println("TENSORFLOW THERMAL OBJECT DETECTION");
    Serial.print("MLX Bus (Wire): SDA: GPIO "); Serial.print(MLX_SDA_PIN);
    Serial.print(", SCL: GPIO "); Serial.println(MLX_SCL_PIN);

    // Initialize MLX90640, passing the standard '&Wire' object
    if (!mlx.begin(MLX90640_I2CADDR_DEFAULT, &Wire)) {
      Serial.println("MLX90640 not found! Check wiring and power.");
      while (1) delay(100);
    }
    // Set refresh rate
    mlx.setRefreshRate(MLX90640_4_HZ);

    // 2. --- I2C Initialization for OPT3001 (Pins 10, 11) ---
    // The custom 'Wire_OPT' object is initialized here.
    Wire_OPT.begin(OPT_SDA_PIN, OPT_SCL_PIN, 100000);
    pinMode(OPT_INT_PIN, INPUT_PULLUP);


    Serial.println("\nOPT3001 Sensor Initialization");
    Serial.print("OPT Bus (Wire_OPT): SDA: GPIO "); Serial.print(OPT_SDA_PIN);
    Serial.print(", SCL: GPIO "); Serial.println(OPT_SCL_PIN);

    // Setup the OPT3001, passing the custom 'Wire_OPT' object
    // 2. --- I2C Initialization for OPT3001 (Pins 10, 11 using Wire_OPT) ---
// ... (Wire_OPT.begin() and pinMode(OPT_INT_PIN) remain here) ...

// Setup the OPT3001, passing the custom 'Wire_OPT' object
if (sensor.setup(Wire_OPT, I2C_ADDRESS) != 0) {
    // If setup fails, we assume a connection issue or wrong address.
    Serial.println("Failed to setup OPT3001. Check I2C bus connection/address.");
} else { // <--- SUCCESS: setup() returned 0 (i.e., NO error)
    // Assume success and proceed directly to configuration
    sensor.config_set(OPT3001_CONVERSION_TIME_100MS);
    sensor.conversion_continuous_enable();
    Serial.println("OPT3001 initialized successfully!");
}
// The redundant 'else' case is now covered by the first 'if' statement.

    // 3. --- TensorFlow Setup ---
    delay(1500); // Give sensors time to stabilize
    tf.setNumInputs(INPUT_SIZE);
    tf.setNumOutputs(4);

    tf.resolver.AddFullyConnected();
    tf.resolver.AddConv2D();
    tf.resolver.AddDepthwiseConv2D();
    tf.resolver.AddReshape();
    
    while (!tf.begin(mlx_sensor_model_quantized).isOk())
        Serial.println(tf.exception.toString());
    
    Serial.println("TensorFlow Model Initialized.");

    // =============================================================
    // ⚡ BLYNK SETUP CODE
    // =============================================================
    Blynk.begin(BLYNK_AUTH_TOKEN, ssid, pass);

    // Set up the timer to call sendSensorDataToBlynk() every 5 seconds (5000 milliseconds)
    // This allows your loop() to run your TFLite model at its own pace.
    timer.setInterval(5000L, sendSensorDataToBlynk); //data sent every 2 seconds to blink
    // =============================================================
}





//-------------------------------------------------------------
// LOOP
//-------------------------------------------------------------
void loop() {
    // =============================================================
    // ⚡ BLYNK LOOP CALLS
    // =============================================================
    Blynk.run();
    timer.run();
    // =============================================================

    float lux;
    delay(150); // Your existing delay to match OPT3001 conversion time

    // Read illuminance in lux
    if (sensor.lux_read(&lux) == 0) {
        // Store the value globally for the Blynk timer to send
        current_lux = lux; 
        // Format the Lux message into the buffer
        snprintf(logBuffer, sizeof(logBuffer), "Illuminance: %.2f lux", current_lux);
        blynkLog(logBuffer); // Send to both Serial and Blynk
    } else {
        // This output confirms the lux read failed (usually due to not being ready).
        blynkLog("Failed to read illuminance (Data not ready or communication error)");
    }



    // Reading interval set to 500ms (half a second)
    // You should ensure this delay is longer than the conversion time (100ms or 800ms)
    //delay(500); // <-- If this delay is needed for your MLX/TFLite speed, keep it!

    // 1. Read thermal data from the MLX90640 sensor
    if (mlx.getFrame(mlx_frame) == 0) {
    
        // 2. Normalize and prepare data for the model
        for (int i = 0; i < INPUT_SIZE; i++) {
            input_image[i] = (mlx_frame[i] - T_MIN) / T_RANGE;
    
            // Safety clamp
            if (input_image[i] < 0.0f) input_image[i] = 0.0f;
            if (input_image[i] > 1.0f) input_image[i] = 1.0f;
        }

        // 3. Run prediction
        if (!tf.predict(input_image).isOk()) {
            Serial.println(tf.exception.toString());
            return;
        }
    
        // 4. Interpret Results
        float xmin = tf.output(0);
        float ymin = tf.output(1);
        float xmax = tf.output(2);
        float ymax = tf.output(3);

        // Calculate the predicted width, height, and area (normalized)
        float width = xmax - xmin;
        float height = ymax - ymin;
        float area = width * height;

        // --- 1A. Bounding Box Area Threshold Check ---
        const float MIN_AREA_THRESHOLD = 0.01f; // Tune this

        if (area > MIN_AREA_THRESHOLD) {
            // A box of sufficient size was detected. Now, verify the temperature.
    
            // Denormalize coordinates
            int pixel_xmin = (int)(xmin * IMG_WIDTH);
            int pixel_ymin = (int)(ymin * IMG_HEIGHT);
            int pixel_xmax = (int)(xmax * IMG_WIDTH);
            int pixel_ymax = (int)(ymax * IMG_HEIGHT);

            //START OF ADDED THERMAL ANALYSIS CODE 
            float total_temp = 0.0f;
            int pixel_count = 0;

            // Loop through the MLX90640's 32x24 grid pixels inside the bounding box
            for (int y = pixel_ymin; y < pixel_ymax; y++) {
                for (int x = pixel_xmin; x < pixel_xmax; x++) {
                    // Safety check to ensure we stay within the 32x24 boundaries
                    if (x >= 0 && x < IMG_WIDTH && y >= 0 && y < IMG_HEIGHT) {
                        // Calculate the 1D index: index = y * width + x
                        int index = y * IMG_WIDTH + x;
    
                        // Add the raw temperature (Celsius) from the MLX frame
                        total_temp += mlx_frame[index];
                        pixel_count++;
                    }
                }
            }

            float avg_temp = (pixel_count > 0) ? (total_temp / pixel_count) : 0.0f;
            
            // Store the value globally for the Blynk timer to send
            current_avg_temp = avg_temp;

            // --- 2C. Temperature Threshold Check ---
            const float HUMAN_TEMP_THRESHOLD = 28.0f; // Tune this

            if (avg_temp > HUMAN_TEMP_THRESHOLD) {
                // Format the full HUMAN DETECTED message
                snprintf(logBuffer, sizeof(logBuffer), 
                "STATUS: HUMAN DETECTED (Avg Temp: %.1f°C) Box: [%.2f,%.2f to %.2f,%.2f]",
                avg_temp, xmin, ymin, xmax, ymax);
                blynkLog(logBuffer);
            } else {
                // Format the full WARM OBJECT message
                snprintf(logBuffer, sizeof(logBuffer), 
                "STATUS: Warm Object (Avg Temp: %.1f°C, not hot enough)",
                avg_temp);
                blynkLog(logBuffer);
            }
            //END OF ADDED THERMAL ANALYSIS CODE 

        } else {
            blynkLog("STATUS: Empty Room / No Significant Detection.");
            // If no detection, set temp to a default/low value
            current_avg_temp = 0.0f; 
        }
    }
    
    // Short delay to keep the system responsive
    delay(10);

}

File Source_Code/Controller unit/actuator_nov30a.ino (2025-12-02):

// ACTUATOR - corrected to actively sync V0 & V1 from server

#define BLYNK_TEMPLATE_NAME "BUBBA"
#define BLYNK_TEMPLATE_ID   "TMPL3WgBo7eIO"
#define BLYNK_DEVICE_NAME   "actuator_deba"
#define BLYNK_AUTH_TOKEN    "O2b45fOqHpsXpWNF1oER5rfkrAiF6SCV"



#include <WiFi.h>
#include <BlynkSimpleEsp32.h>
#include "Blynk/BlynkTimer.h"

#define VIRTUAL_PIN_TERMINAL_ACTUATOR V9

char logBufferActuator[256];

// Simple logging helper: Serial + (optionally) Terminal widget
void blynkLogActuator(const char* message) {
    Serial.println(message);
    // If V9 exists in your project as a terminal/label, this will show it there
    //Blynk.virtualWrite(VIRTUAL_PIN_TERMINAL_ACTUATOR, message);
}

// Wi-Fi credentials
char ssid[] = "ERROR";
char pass[] = "skansal937";

const int LED_PIN = 2;
const float HUMAN_TEMP_THRESHOLD = 28.0f;

float receivedLux = 0.0f;
float receivedAvgTemp = 0.0f;

BlynkTimer actuatorTimer; // timer for periodic syncs

// Called when server pushes V0 (lux)
BLYNK_WRITE(V0) {
    receivedLux = param.asFloat();
    snprintf(logBufferActuator, sizeof(logBufferActuator), "V0 Lux Received: %.2f", receivedLux);
    blynkLogActuator(logBufferActuator);
}

// Called when server pushes V1 (avg temp)
BLYNK_WRITE(V1) {
    receivedAvgTemp = param.asFloat();
    snprintf(logBufferActuator, sizeof(logBufferActuator), "V1 Temp Received: %.1f°C", receivedAvgTemp);
    blynkLogActuator(logBufferActuator);

    if (receivedAvgTemp > HUMAN_TEMP_THRESHOLD) {
        digitalWrite(LED_PIN, HIGH);
        blynkLogActuator("-> LED ON: Human Temp Threshold Exceeded!");
    } else {
        digitalWrite(LED_PIN, LOW);
        blynkLogActuator("-> LED OFF: Temperature is below threshold.");
    }
}

// This runs when Blynk connection is established/re-established
BLYNK_CONNECTED() {
    // Ask server to send current values for V0 & V1 right away
    Blynk.syncVirtual(V0);
    Blynk.syncVirtual(V1);

    blynkLogActuator("Blynk Connected: synced V0 & V1");
}

// Periodic sync function (keeps actuator in sync with detector)
void periodicSync() {
    // This forces the server to push the latest datastream values to this device
    Blynk.syncVirtual(V0);
    Blynk.syncVirtual(V1);
    Serial.println("Periodic sync requested (V0 & V1).");
}

void setup() {
    Serial.begin(115200);
    delay(1000);

    pinMode(LED_PIN, OUTPUT);
    digitalWrite(LED_PIN, LOW);

Serial.print("Connecting to WiFi: ");
Serial.println(ssid);


unsigned long start = millis();
while (WiFi.status() != WL_CONNECTED) {
    delay(500);
    Serial.print(".");
    if (millis() - start > 10000) {
        Serial.println("WiFi failed!");
        break;
    }
}
Serial.println();
Serial.print("IP Address: ");
Serial.println(WiFi.localIP());



    // Connect to Blynk (auth token, ssid, pass)
    Blynk.begin(BLYNK_AUTH_TOKEN, ssid, pass);

    // Setup a timer to call periodicSync every 2 seconds (adjust if needed)
    actuatorTimer.setInterval(5000L, periodicSync);

    blynkLogActuator("Actuator setup complete. Waiting for Blynk...");
}

void loop() {
Serial.print("WiFi Status: ");
Serial.println(WiFi.status());

    Blynk.run();
    actuatorTimer.run();
}

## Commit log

2025-10-20 new commit at 02:53 PM @20th october 2025
    Schematics, Layouts and 3D models
2025-10-20 Update README with Power-supply section and images
    Added a Power-supply section and updated images in README.
2025-10-20 Update Mainboard image and add Power supply section
    Updated images for Mainboard and added Power supply section.
2025-10-20 Update README with more images for components
    Added additional images for Mainboard, Controller, and Power supply sections.
2025-10-20 Fix image links for Mainboard PCB in README
    Updated image links for the Mainboard PCB in README.
2025-10-20 Comment out unused images in README
    Commented out unused image links for mainboard, controller, and power supply.
2025-10-20 Add initial Power Supply documentation
2025-10-20 Mainboard init commit KiCad files
    KiCad files
    [Mainboard.kicad_pcb, Mainboard.kicad_sch, bom.csv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]
2025-10-20 Controller init KiCad files
    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
    [Controller.kicad_pcb, Controller.kicad_sch, bom.csv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]
2025-10-20 Power supply init KiCad files
    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
    [Power_supply.kicad_pcb, Power_supply.kicad_sch]

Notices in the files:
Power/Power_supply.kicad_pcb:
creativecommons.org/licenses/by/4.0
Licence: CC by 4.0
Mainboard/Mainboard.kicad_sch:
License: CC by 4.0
